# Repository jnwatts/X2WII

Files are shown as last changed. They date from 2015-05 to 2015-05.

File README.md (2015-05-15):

# X2WII
Adapt Gamecube/N64 controllers as Wii-mote extensions

My own implementation of [Raphaël Assénat][http://www.raphnet.net/contact/contact_en.php]'s [Extenmote][http://www.raphnet.net/electronique/extenmote/index_en.php].

#Licenses
All sofware and hardware found within this repository is released under version 3 of the [GPL][http://www.gnu.org/licenses/gpl-3.0.txt].

PDFs found in the Docs folder are copywrite their original owners and to the best of my knowledge may be shared un-modified.

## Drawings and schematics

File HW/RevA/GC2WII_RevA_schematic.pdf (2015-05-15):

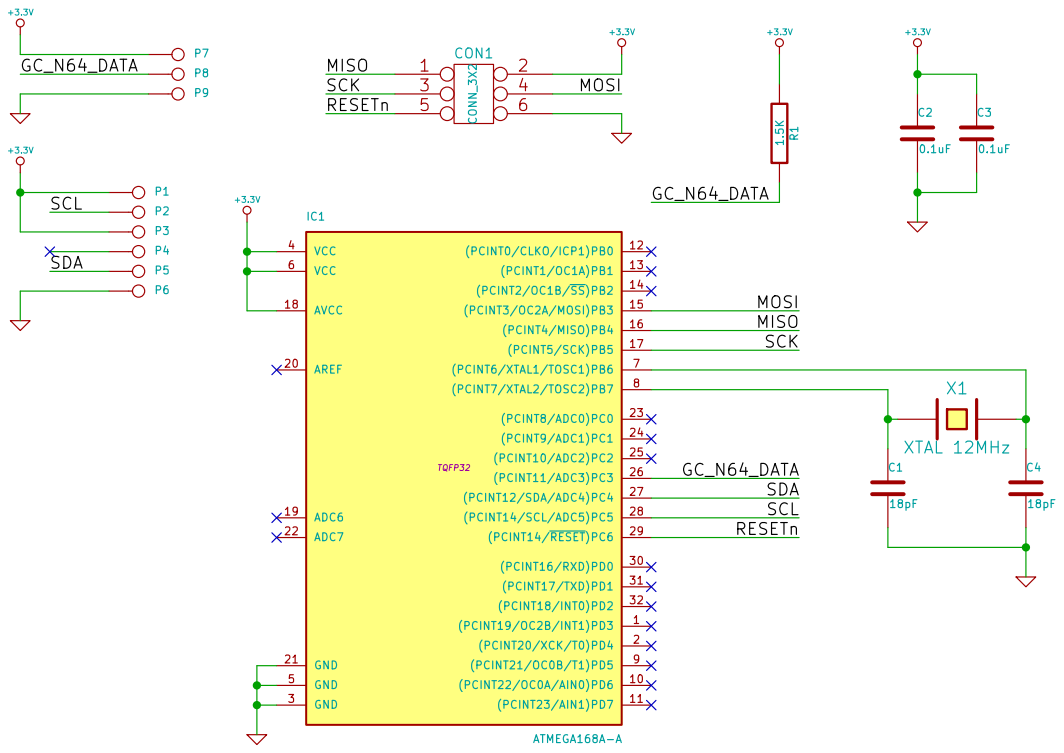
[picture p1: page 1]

Id: 1/1 Title: File: GC2WII.sch
Sheet: /

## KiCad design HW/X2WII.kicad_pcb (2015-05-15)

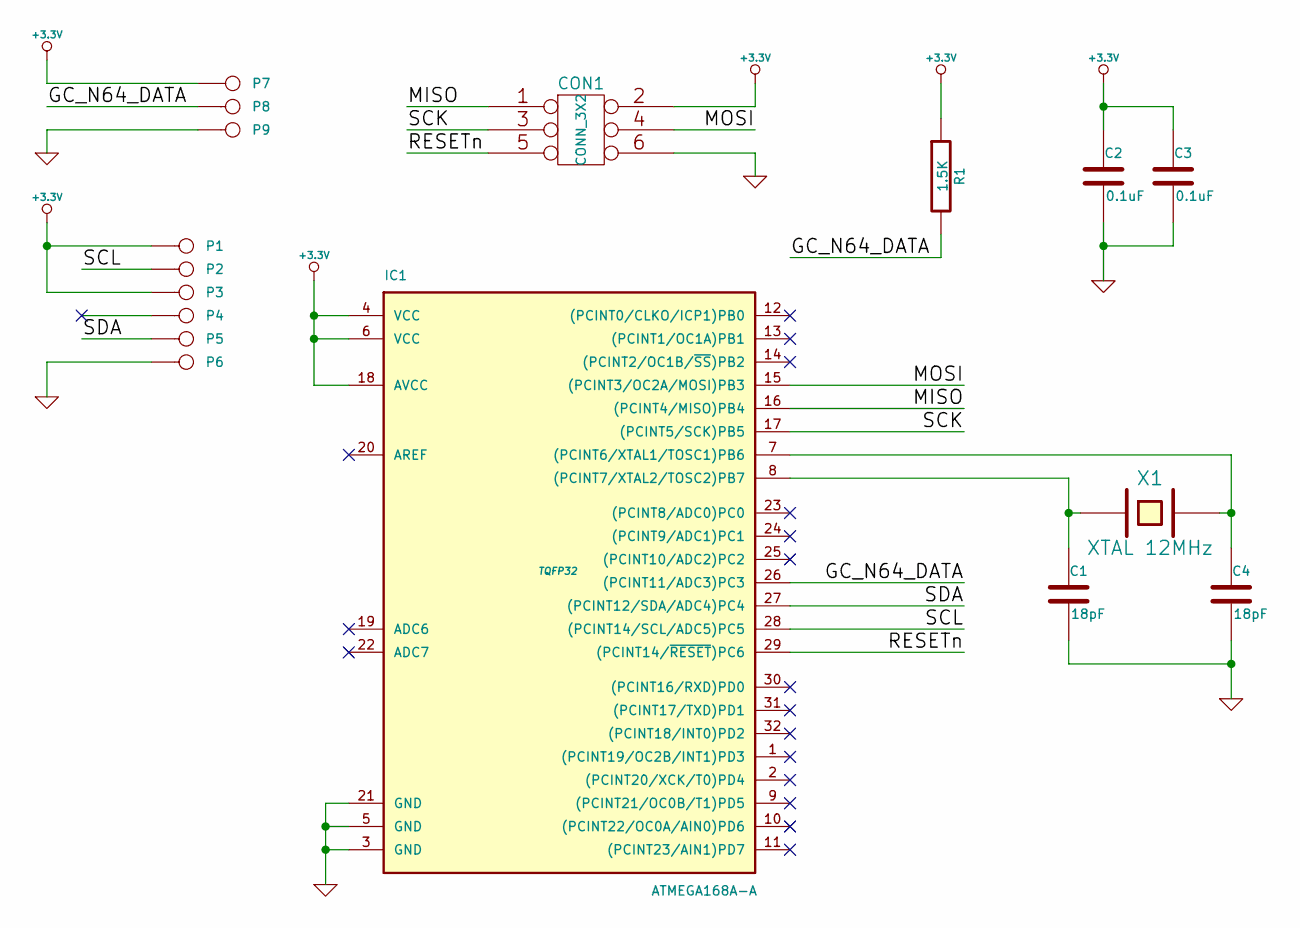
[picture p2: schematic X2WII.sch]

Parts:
C1, C4: 18pF
C2, C3: 0.1uF
CON1: CONN_3X2
IC1: ATMEGA168A-A; TQFP32
P1, P2, P3, P4, P5, P6, P7, P8, P9: CONN_1
R1: 1.5K
X1: XTAL 12MHz

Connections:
+3.3V: C2.1, C3.1, CON1.2, IC1.4 (VCC), IC1.6 (VCC), IC1.18 (AVCC), P1.1, P3.1, P7.1, R1.1
/GC_N64_DATA: IC1.26 ((PCINT11/ADC3)PC3), P8.1, R1.2
/MISO: CON1.1, IC1.16 ((PCINT4/MISO)PB4)
/MOSI: CON1.4, IC1.15 ((PCINT3/OC2A/MOSI)PB3)
/RESETn: CON1.5, IC1.29 ((PCINT14/~RESET~)PC6)
/SCK: CON1.3, IC1.17 ((PCINT5/SCK)PB5)
/SCL: IC1.28 ((PCINT14/SCL/ADC5)PC5), P2.1
/SDA: IC1.27 ((PCINT12/SDA/ADC4)PC4), P5.1
GND: C1.2, C2.2, C3.2, C4.2, CON1.6, IC1.3 (GND), IC1.5 (GND), IC1.21 (GND), P6.1, P9.1
unnamed: C4.1, IC1.7 ((PCINT6/XTAL1/TOSC1)PB6), X1.2
unnamed: C1.1, IC1.8 ((PCINT7/XTAL2/TOSC2)PB7), X1.1

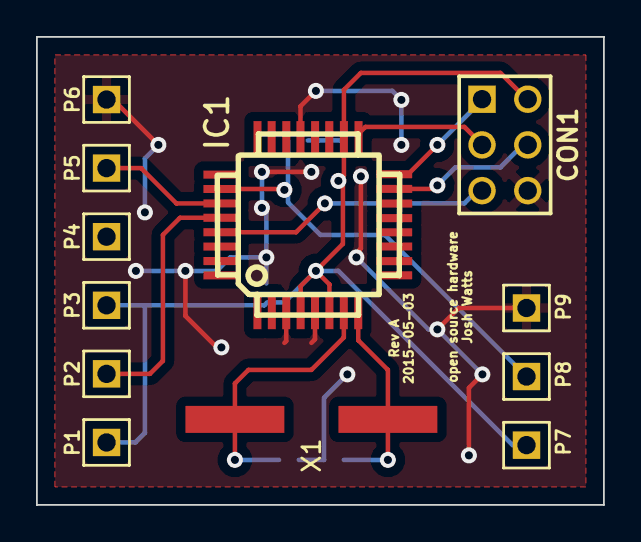
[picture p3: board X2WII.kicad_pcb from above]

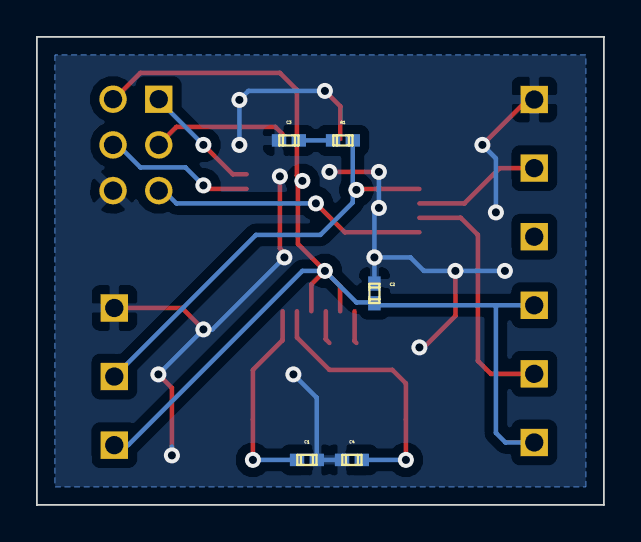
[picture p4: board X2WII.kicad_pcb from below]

Board: 2 copper layers, 31.5 x 26.0 mm, 17 parts (5 on the bottom side), 11 nets.

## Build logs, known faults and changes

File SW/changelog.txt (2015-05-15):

-v1.9.7
 L/R analogic sliders fix and improvements:
   - N64/SNES: Simulate full L/R analogic deflection when L/R are pressed.
   - Gamecube: Fix L/R analog sliders support (broken since 1.9!)

-v1.9.6
 - Fix NES/SNES controller support (was broken in v1.9.5)

-v1.9.5
 - New Gamecube button mapping
 - Triple click on START button now triggers the HOME button (SNES/NES/GC/N64)
 - Prevent a 8 bit overflow from occuring with some cheap controller clones.
   Fixes the "joystick left/down direction does not work" problem, but keep
   in mind the overall quality of the controller won't increase. It will
   work as bad as it does on a real N64.
 - Fix N64/Gamecube communication timing
 - Fix eeprom init bug (Last mapping not saved)
 - Improved controller auto-detection

-v1.9 -- Improved raw data feature
 - Added raw data for SNES and NES controllers
 - Implemented a special mode where the extension ID changes with the
   connected controller.
 - Modified GC/N64 raw data feature to includes the button data too and
   to be exactly in the format received from the controller.
Technical details here: http://www.raphnet.net/programmation/extenmote_raw/index_en.php

-v1.8
 - [GC/N64] Raw analog data and a signature is now appended to the standard
   classic controller report structure. Software that is aware of this
   will be able to use the full resolution of the original joysticks.

-v1.7
 - [GC] Added a gamecube mappings (for Devolution)
 - [GC] Added a gamecube button combination to trigger the home button (A+B+Y+X+Z+C-Down)
 - [GC] Implemented gamecube L and R sliders
 - [GC/N64] Holding start when connecting the controller (or powering up)
   disables the button mapping combos for the session.

-v1.6
 - Add two N64 mappings for F-Zero X and Yoshi's Story
 - Add a tool I use for QA (Requires Linux and a wusbmote adapter)
 - The N64 Default curve (1.5) was not really active by default. L+R+Z+A had
   to be explicitely pressed. (now fixed)
 - Fix calibartion data for libOGC (Fixes wii64 and probably others)
 - N64: When mapping 0 is active, pressing the four C buttons + Dpad left + Z
   sends X+Y pressed status (for wii64 menu)

-v1.5
 - New v1.5 default curve (much better in Zelda)
 - When switching from the Wii menu to a game, the adapter does not
   have to be reconnected anymore.
 - Fixed the 'always scrolling' bug that occured in the Wii U main menu (Wii
   menu was ok)
 - Removed the old v1.1 curve

-v1.4.1
 - Use the configured N64 curve for real

-v1.4
 - Implemented a better Gamecube conversion curves
 - Added two gamecube mappings
 - Two N64 transfer curves now available (the default works better with
 normally worn controllers)\
 - The adapter now remembers and restores the last settings that have been
 used.

-v1.3
 - Implemented a new gamecube mapping to help SNES games
 - Finished Gamecube C stick implementation.
 (Gamecube L/R analog part still not implemented. I need a game
 that uses it to test)

-v1.2
 - PORTD4 must be kept high for low power consumption on builds using the
 multiuse PCB2:
 (http://www.raphnet.net/electronique/multiuse_pcb2/index_en.php)

-v1.1
 - Use a reverse lookup table for the N64 to VC transfer function

-v1.0

Supported:
 - N64 support with 6 mappings
 - SNES support with 3 mappings: Tested SNS-005
 - NES controller support: Tested Standard controllers (NES-004), NES MAX (NES-027)
 - Tested with several NES, SNES and N64 virtual console titles as well as
   Mario Kart Wii.

Known issues:
 - Some NES controllers won't work due to the 3.3v supply
   (ex: NES Advantage)
 - Gamecube support incomplete (missing analogic L/R sliders)

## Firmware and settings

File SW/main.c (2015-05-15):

/*  Extenmote : NES, SNES, N64 and Gamecube to Wii remote adapter firmware
 *  Copyright (C) 2012-2014  Raphael Assenat <raph@raphnet.net>
 *
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
 *  You should have received a copy of the GNU General Public License
 *  along with this program.  If not, see <http://www.gnu.org/licenses/>.
 */

#include <avr/io.h>
#include <avr/sleep.h>
#include <avr/interrupt.h>
#include <math.h>
#include "wiimote.h"
#include "gcn64_protocol.h"
#include "snes.h"
#include "n64.h"
#include "gamecube.h"
#include "eeprom.h"
#include "classic.h"
#include "analog.h"

static unsigned char classic_id[6] = { 0x00, 0x00, 0xA4, 0x20, 0x01, 0x01 };
static unsigned char adapter_n64_id[6] = { 0x00, 0x00, 0xA4, 0x20, 0x52, 0x64 };
static unsigned char adapter_gc_id[6] = { 0x00, 0x00, 0xA4, 0x20, 0x52, 0x47 };
static unsigned char adapter_snes_id[6] = { 0x00, 0x00, 0xA4, 0x20, 0x52, 0x10 };
static unsigned char adapter_nes_id[6] = { 0x00, 0x00, 0xA4, 0x20, 0x52, 0x08 };

// Classic controller (1)
// e1 15 82  e3 1a 7e  e3 1d 82  e4 1a 81  1a 18  7b d0
// Classic controller (2)
// e1 1b 7e  ea 1b 83  e5 1b 82  e4 16 80  26 22  9b f0
//

static unsigned char cal_data[32] = { 
		0xE0, 0x20, 0x80, // Left stick: Max X, Min X, Center X
		0xE0, 0x20, 0x80, // Left stick: Max Y, Min Y, Center Y
		0xE0, 0x20, 0x80, // Right stick: Max X, Min X, Center X
		0xE0, 0x20, 0x80, // Right stick: Max Y, Min Y, Center Y
		0x00, 0x00, 0, 0, 	// Shoulder Max? Min? checksum?

		0xE0, 0x20, 0x80, // Left stick: Max X, Min X, Center X
		0xE0, 0x20, 0x80, // Left stick: Max Y, Min Y, Center Y
		0xE0, 0x20, 0x80, // Right stick: Max X, Min X, Center X
		0xE0, 0x20, 0x80, // Right stick: Max Y, Min Y, Center Y
		0x00, 0x00, 0, 0,	// Shoulder Max? Min? checksum?
};

static volatile char performupdate;

static void hwInit(void)
{
	/* PORTC
	 *
	 * 0: SNES/NES CLK 		out1
	 * 1: SNES/NES LATCH	out1
	 * 2: SNES/NES DATA		in-pu
	 * 3: N64/Gamecube IO	in-pu
	 * 4: SDA (io)
	 * 5: SCL (io)
	 * 6: N/A
	 * 7: N/A
	 *
	 * [*] Needs an external 1.5k pullup.
	 *
	 */
	PORTC = 0x07;
	DDRC = 0xc3;

	/* PORTB
	 *
	 * 0: out0
	 * 1: out0
	 * 2: out0
	 * 3: out0
	 * 4: out0
	 * 5: out0
	 * 6: out0
	 * 7: out0
	 *
	 */
	PORTB = 0x00;
	DDRB = 0xff;

	/* PORTD
	 * 0: out0
	 * 1: out0
	 * 2: out0
	 * 3: out0
	 * 4: out1 // Tied to VCC on Multiuse PCB2 for routing reasons
	 * 5: out0
	 * 6: out0
	 * 7: out0
	 */
	PORTD = 0x10;
	DDRD = 0xff;
}

static char initial_controller = PAD_TYPE_NONE;

static void do_earlyDetection()
{
	Gamepad *snes_gamepad = NULL;
	unsigned char ngc;
	gamepad_data snesdata;

//			initial_controller = PAD_TYPE_N64;
//			wm_setAltId(adapter_n64_id);
//			return;
#if defined(WITH_N64) || defined(WITH_GAMECUBE)
	ngc = gcn64_detectController();
	switch(ngc)
	{
		case CONTROLLER_IS_N64:
			initial_controller = PAD_TYPE_N64;
			wm_setAltId(adapter_n64_id);
			return;

		case CONTROLLER_IS_GC:
			initial_controller = PAD_TYPE_GAMECUBE;
			wm_setAltId(adapter_gc_id);
			return;
	}
#endif

	snes_gamepad = snesGetGamepad();
	snes_gamepad->update();
	snes_gamepad->getReport(&snesdata);

	if (snesdata.pad_type == PAD_TYPE_SNES) {
		initial_controller = PAD_TYPE_SNES;
		wm_setAltId(adapter_snes_id);
	} else {
		initial_controller = PAD_TYPE_NES;
		wm_setAltId(adapter_nes_id);
	}
}


static void pollfunc(void)
{
	performupdate = 1;
}

#define ERROR_THRESHOLD			10

#define STATE_NO_CONTROLLER		0
#define STATE_CONTROLLER_ACTIVE	1

#define N64_GC_DETECT_PERIOD	120

int main(void)
{
	Gamepad *snes_gamepad = NULL;
	Gamepad *n64_gamepad = NULL;
	Gamepad *gc_gamepad	= NULL;
	Gamepad *cur_gamepad = NULL;
	unsigned char mainState = STATE_NO_CONTROLLER;
	unsigned char analog_style = ANALOG_STYLE_DEFAULT;
	gamepad_data lastReadData;
	classic_pad_data classicData;
	unsigned char current_report[PACKED_CLASSIC_DATA_SIZE];
	int error_count = 0;
	char first_controller_read=0;
	int detect_time = 0;

	hwInit();
	init_config();
#if defined(WITH_N64) || defined(WITH_GAMECUBE)
	gcn64protocol_hwinit();
#endif

#ifdef WITH_SNES
	snes_gamepad = snesGetGamepad();
#endif

#ifdef WITH_N64
	n64_gamepad = n64GetGamepad();
#endif

#ifdef WITH_GAMECUBE
	gc_gamepad = gamecubeGetGamepad();
#endif

	dataToClassic(NULL, &classicData, 0);
	pack_classic_data(&classicData, current_report, ANALOG_STYLE_DEFAULT);

	do_earlyDetection();

	wm_init(classic_id, current_report, PACKED_CLASSIC_DATA_SIZE, cal_data, pollfunc);
	wm_start();
	sei();

	while(1)
	{
		// Adapter without sleep: 4mA
		// Adapter with sleep: 1.6mA

		set_sleep_mode(SLEEP_MODE_EXT_STANDBY);
		sleep_enable();
		sleep_cpu();
		sleep_disable();

		while (!performupdate) { }
		performupdate = 0;

		// With this delay, the controller read is postponed until just before
		// the next I2C read from the wiimote. This is to reduce latency to a
		// minimum (2.2ms at the moment).
		//
		// The N64 or Gamecube controller read will be corrupted if interrupted
		// by an I2C interrupt. The timing of the I2C read varies (menu vs in-game)
		// so we have to be careful not to let the N64/GC transaction overlap
		// with the I2C communication..
		//
		// This is why I chose to maintain a margin.
		//
		_delay_ms(2.35); // delay A

		//                                        |<----------- E ----------->|
		//                               C  -->|  |<--
		//         ____________________________    ________  / ______________________ ...
		// N64/GC:                             ||||         /
		//         _____  __    __    ___________________  / ____  __    __    _____ ...
		// I2C:         ||  ||||  ||||                    /      ||  ||||  ||||
		//                                               /
		//              |<---- D --->|
		//                      |<----- A ---->|
		//              |<-------------------B------------------>|
		// A = 2.35ms (Configured above)
		// B = 5ms (Wiimote classic controller poll rate)
		// C = 0.4ms (GC controller poll time)
		// D = 1.2ms, 1.1ms, 1.5ms (Wiimote I2C communication time. Varies [menu/game])
		// E = 2.34ms (menu), 2.84ms (in game)
		//

		switch(mainState)
		{
			default:
				mainState = STATE_NO_CONTROLLER;
				break;

			case STATE_NO_CONTROLLER:
				disable_config = 0;
				first_controller_read = 1;
#if defined(WITH_GAMECUBE) || defined(WITH_N64)
				detect_time++;
				if (detect_time > N64_GC_DETECT_PERIOD)
				{
					detect_time = 0;
					switch (gcn64_detectController())
					{
						case CONTROLLER_IS_N64:
							cur_gamepad = n64_gamepad;
							mainState = STATE_CONTROLLER_ACTIVE;
							analog_style = ANALOG_STYLE_N64;
							break;

						case CONTROLLER_IS_GC:
							cur_gamepad = gc_gamepad;
							mainState = STATE_CONTROLLER_ACTIVE;
							analog_style = ANALOG_STYLE_GC;
							break;
					}
				}
#endif
				snes_gamepad->update();
				snes_gamepad->getReport(&lastReadData);
				break;

			case STATE_CONTROLLER_ACTIVE:
				if (cur_gamepad->update()) {
					error_count++;
					if (error_count > 10)
						mainState = STATE_NO_CONTROLLER;
					break;
				}
				error_count = 0;
				cur_gamepad->getReport(&lastReadData);
				if (first_controller_read)
					first_controller_read++;
				break;
		}

		if (!wm_altIdEnabled())
		{
			dataToClassic(&lastReadData, &classicData, first_controller_read);
			if (first_controller_read > 2) {
				first_controller_read = 0;
			}
			pack_classic_data(&classicData, current_report, analog_style);
			wm_newaction(current_report, PACKED_CLASSIC_DATA_SIZE);
		}
		else
		{
			unsigned char raw[8];

			// Changing controller is not possible in this mode
			// unless we control the device_detect line.
			if (lastReadData.pad_type != initial_controller)
				 continue;

			switch (initial_controller)
			{
				case PAD_TYPE_GAMECUBE:
					memcpy(raw, lastReadData.gc.raw_data, sizeof(lastReadData.gc.raw_data));
					wm_newaction(raw, sizeof(lastReadData.gc.raw_data));
					break;

				case PAD_TYPE_N64:
					memcpy(raw, lastReadData.n64.raw_data, sizeof(lastReadData.n64.raw_data));
					wm_newaction(raw, sizeof(lastReadData.n64.raw_data));
					break;

				case PAD_TYPE_SNES:
					memcpy(raw, lastReadData.snes.raw_data, sizeof(lastReadData.snes.raw_data));
					wm_newaction(raw, sizeof(lastReadData.snes.raw_data));
					break;

				case PAD_TYPE_NES:
					memcpy(raw, lastReadData.nes.raw_data, sizeof(lastReadData.nes.raw_data));
					wm_newaction(raw, sizeof(lastReadData.nes.raw_data));
					break;
			}

			// TODO : Controller specific report format
		}
	}

	return 0;
}

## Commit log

2015-05-15 Add SW folder, from extenmote-1.9.7.tar.gz (sha1: 64821ca3ca6409671b4b65d9664a1e5b004dce34)
    [transfer.ods]
2015-05-15 Renamed from GC2WII to X2WII
    [X2WII.kicad_pcb, X2WII.sch]
2015-05-15 Add Rev A HW
    [GC2WII-B_Cu.gbl, GC2WII-B_Mask.gbs, GC2WII-B_SilkS.gbo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]
2015-05-15 Add Makefile to build firmware and flash board

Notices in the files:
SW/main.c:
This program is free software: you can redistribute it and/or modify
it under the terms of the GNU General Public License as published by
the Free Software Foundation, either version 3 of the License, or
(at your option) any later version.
